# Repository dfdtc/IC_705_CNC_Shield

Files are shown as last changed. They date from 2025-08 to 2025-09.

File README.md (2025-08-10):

## Other languages
- zh_CN [简体中文](README.zh_CN.md)

## Project Overview

This project provides a set of optional features, is highly extensible, and offers a cost‑effective model for an ICOM IC‑705 device shield kit.

---

## Repository & File Structure

This project contains many derived model files, along with some reference models. Therefore: **Please do not simply send the whole folder to a fabrication shop; otherwise you will receive several sets of shields with different configurations and the manufacturing cost will be extremely high.**

### Path Structure

#### Accessories

```
Accessories
```

This folder contains some custom machining accessories as well as modeled standard parts for commercial use (e.g., 4020 aluminum angle code). Purchase or place orders for CNC machining as needed.

#### Machined Parts

```
BasePlate
TopPlate
Handle
```

These files all require CNC machining; order according to the BOM quantities.

#### Aluminum Profile Supports

```
SupportColumn-支撑柱
```

This folder contains model files for aluminum profile supports. They are provided only as references and should not be sent to a CNC or 3D printer.

#### Assembly Explosions & Reference Finished Models

```
AssembleReference
```

This folder contains assembly exploded views and finished product models. They are for reference only and should not be sent to a CNC or 3D printer.

### Naming Convention

Additional features of the derived models are distinguished by suffixes separated with an underscore “_”, e.g.:

- `"底板_开快装板螺纹底孔"` = ordinary base plate + flat-head screw holes + standard tripod quick‑mount threaded bottom holes
- `"底板_开快装板螺纹底孔_沉头_自立"` = self‑standing base plate + countersunk screw holes + standard tripod quick‑mount threaded bottom holes

## Part Machining Recommendations

### 1. Fabrication Notes

#### 1.1  
Because some outsourcing factories provide free edge chamfering / deburring (e.g., CNC-Ai), the top and bottom plate models have no edge chamfers. Pay attention to whether your chosen factory offers this service.

#### 1.2  
The handle model is provided in both un‑chamfered & non‑countersunk versions, as well as chamfered & countersunk variants.

#### 1.3  
Two screw designs are included: tapered countersink and no‑countersink (suitable for cup heads or flat-head screws). Countersunk designs look cleaner but cost a bit more; the no‑countersink version is cheaper but leaves a protruding screw head cap.

#### 1.4  
CNC shops usually offer anodizing and painting, but off‑the‑shelf aluminum profiles may not be available in all colors (see section 2.3). Configure surface treatment options yourself.

#### 1.5  
The handle model is thick and contains a large chamfer; CNC machining time can be long. If cost is an issue, consider 3D printing—strength requirements are fully met.

#### 1.6  
The top plate has M4 holes for fixing the finished Picatinny rails (3/7/11 slots). It’s recommended to thread these yourself during fabrication.

#### 1.7  
Because the base plate is thick, tripod screws cannot directly lock into pre‑machined threaded holes on the machine. Therefore, the base plate offers two configurations: `"开快装板螺纹底孔"` and `"脚架位避让"`.  
- The former already has a 1/4‑20 bottom hole; if your factory supports imperial threading, you can let them thread it, or take the semi‑finished part back to finish it yourself.  
- The latter opens a circular cutout (3.2 cm diameter) at the original tripod screw position, allowing some round mounting brackets to fit into this cutout.

### 2. Aluminum Profile Supports

#### 2.1  
The “EU‑standard 1020 rail” and “EU‑standard 1040 rail” models in the package are only references; do not send them for CNC machining. Find a Taobao shop that cuts 85–88 mm long profiles (the original design is 84.7 mm, so 86/87 mm is recommended to account for machining tolerance and part clearance). Drill holes: M5 on the 1020 rail, M4 on the 1040 rail.

#### 2.2  
Four 1020 rails are required; one 1040 rail is optional and provides extra mounting points and structural support.

#### 2.3  
Commercially available aluminum rails are usually anodized in natural color (some sellers offer black EU‑standard 1020 rails, but not yet for 1040). If you want uniform color, paint as needed, or ask the shop that supplies the profile to provide anodizing/coloring services.

### 3. Installation Notes

#### 3.1  
Because the IC‑705 body bottom is not level, the base plate must have at least a 1.5–2 mm rubber pad around each of the four mounting holes, or use similar thickness rubber washers to achieve sufficient clearance. Otherwise, tightening the mounting screws will impose stress on the machine and the base plate.

### 4. Custom Reference Assembly

#### Derived Model Combination

```
"底板_脚架位避让_沉头_自立" + "顶板_沉头_自立" + "手握_倒角_沉头"
```

#### Factory Choices

- Base/Top Plate: CNC-Ai
- Handle: JLC-CNC (Note: You can also choose CNC-Ai)  
- Antenna Bracket: JLC Sheet Metal  
- Vertical Column: Any Taobao/AliExpress vendor

**Manufacturing Cost (In China, Unit:CNY)**

| Item | Unit Price | Qty | Total |
|---|---|---|---|
| Top Plate | 43 ¥ | 1 | 43 ¥ |
| Bottom Plate | 43 ¥ | 1 | 43 ¥ |
| Handle | 11 ¥ | 2 | 22 ¥ |
| 1020 aluminum post (incl. machining) | 5.3 ¥ | 4 | 21.2 ¥ |
| 1040 aluminum post (incl. machining) | 5.3 ¥ | 1 | 5.3 ¥ |
| Rubber pad | 8 ¥ | 1 | 8 ¥ |
| Fasteners | – | – | ≈30 ¥ |
| Support foot | 12 ¥ | 1 | 12 ¥ |
| **Total** | | | **≈180 ¥** |

#### Tips

I have also 3D‑printed an engineering prototype myself, but I do **not** recommend using 3D printing for this project. The design is optimized for metal CNC; if you wish to use 3D printing, consider other open‑source 3D‑printable shield projects.

---

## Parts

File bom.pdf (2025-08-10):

料名 | 数量 | 用途 | 备注 | 米思米参考料号 | 是否可选
欧标1020铝导轨 | 4 | 立柱，手把安装 | 孔攻丝M5，长度>85mm，建议86/87mm | HFSFIN5-1020
欧标1040铝导轨 | 1 | 立柱 | 孔攻丝M4，长度>85mm，建议86/87mm，可不安装 | | √
20滑块螺母 M5（10x10） | 6+X | 安装手把，以及挂载自定义配件 | 至少买6个 | LNSN6-20-5-100P
橡胶垫 2mm厚，20mm宽 | 合计>6cm | 垫高机器底面 | 多买点吧 | RBNMA2-300
M4 12mm长 6mm头径 | 8 | 机器固定，1040立柱锁定 | 注意为非标头径沉头 | TSARA4-12
M5 12mm长 8mm头径 | 6 | 安装手把 | 注意为非标头径沉头 | TSARA5-12
M5 12mm长 8mm头径 | 16 | 1020立柱锁固 | 注意为非标头径沉头，可以适当选长一点 | TSARA5-15
笔记本电脑支撑脚 | 2 | 垫高机器 | 想买哪款买哪款，基本上都能装
BNC转接头 | X | | 如选择制作转接板，则需要，推荐法兰转接头 | | √
4020铝角码 | X | | 用于固定自定义配件，或装载转接板 | | √
皮卡汀尼导轨 | 1/2 | | 可不安装，自选合适配件，孔距为3/6（竖装）/8CM（横装） | | √
料名 | 数量 | 用途 | 备注 | 是否可选
手握 | 2 | 手把 | | √
顶板 | 1 | 主体结构件
底板 | 1 | 主体结构件
天线板 | 1 | 固定M/N/BNC/SMA四种转接头 | | √
M头天线架 | 1 | 固定M/N四种转接头，二选一 | | √

型材/标准件

机加工件

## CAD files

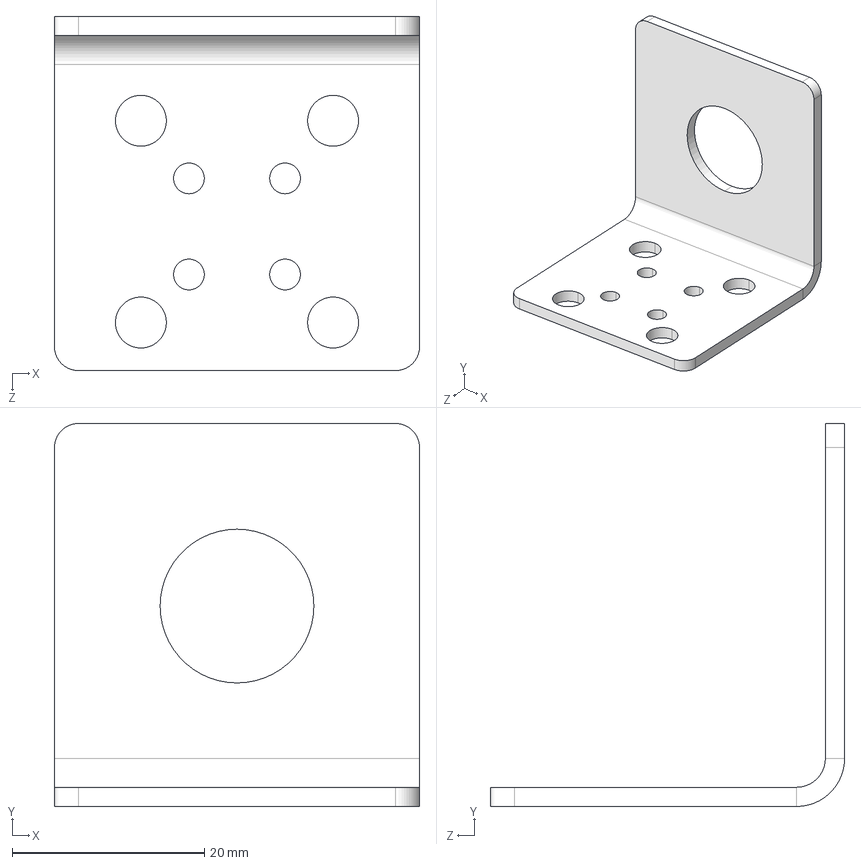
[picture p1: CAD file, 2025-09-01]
Accessories/M头天线架.STEP
38.0 x 39.9 x 36.9 mm

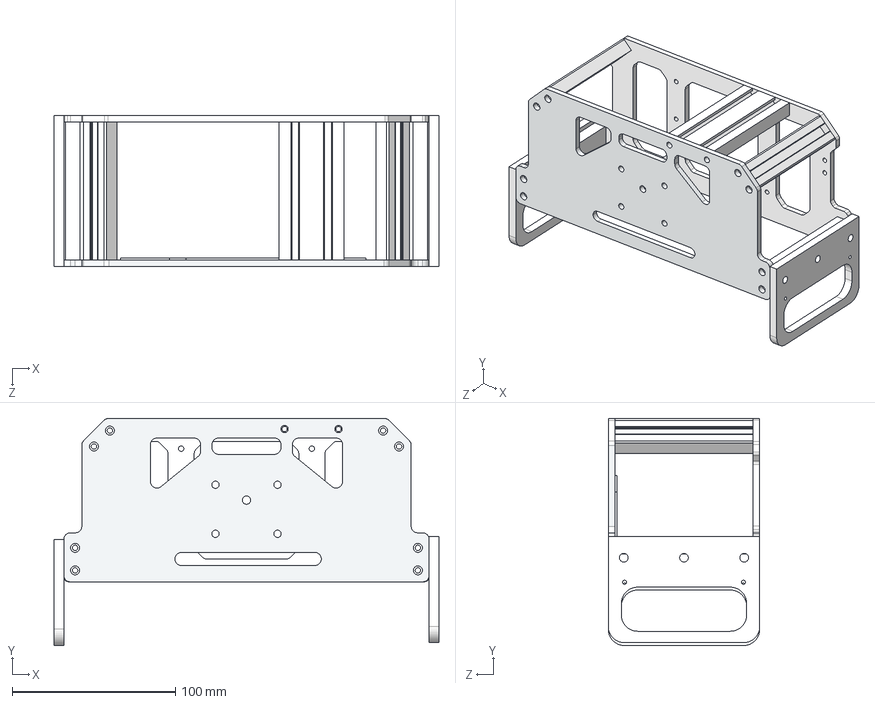
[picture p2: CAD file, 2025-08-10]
AssembleReference/兔笼.STEP
235.6 x 139.0 x 92.7 mm
菁啣V3
階啣V3
欧标1020导轨 x 4
欧标1040导轨
忒挍 x 2
菜え

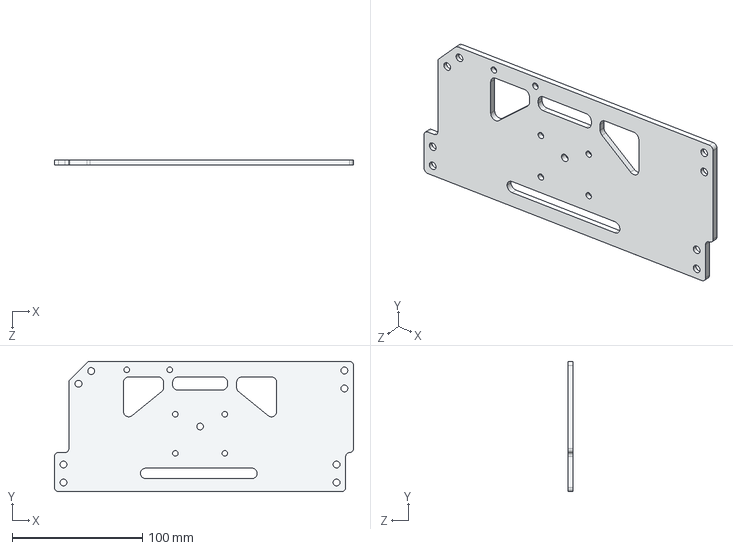
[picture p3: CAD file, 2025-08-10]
BasePlate/底板_开快装板螺纹底孔_沉头_自立.STEP
229.6 x 100.0 x 4.00 mm

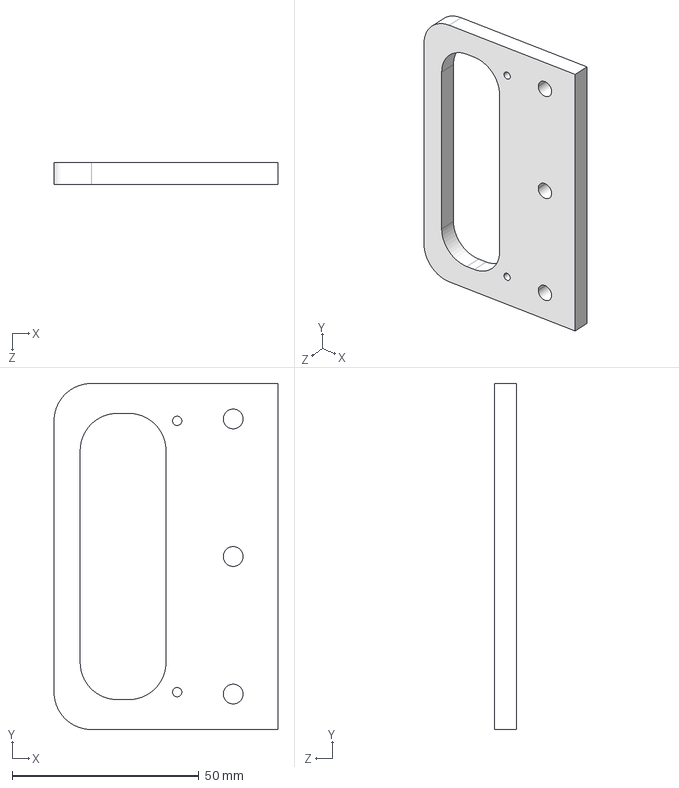
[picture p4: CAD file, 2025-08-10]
Handle/手握.STEP
60.0 x 92.7 x 6.00 mm

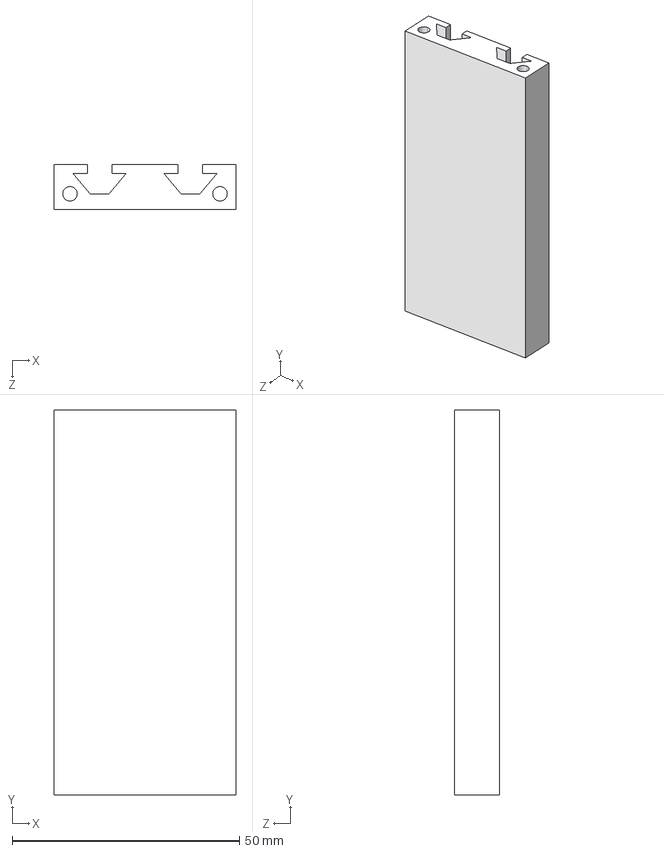
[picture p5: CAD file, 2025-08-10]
SupportColumn/欧标1040导轨.STEP
40.0 x 84.7 x 10.0 mm

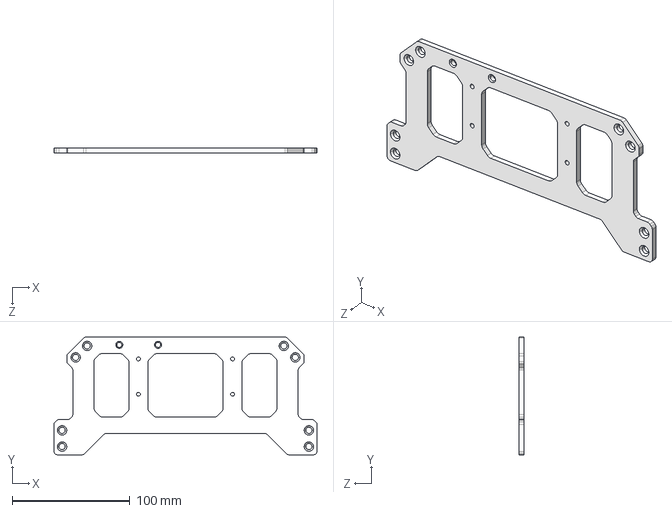
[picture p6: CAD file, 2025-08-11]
TopPlate/顶板_沉头_无天线座固定孔.STEP
223.6 x 100.0 x 4.00 mm

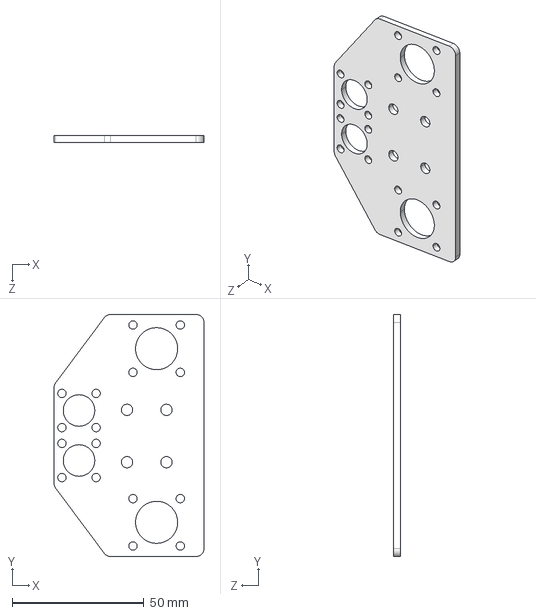
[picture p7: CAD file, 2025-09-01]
Accessories/天线板.STEP
57.0 x 92.0 x 2.50 mm

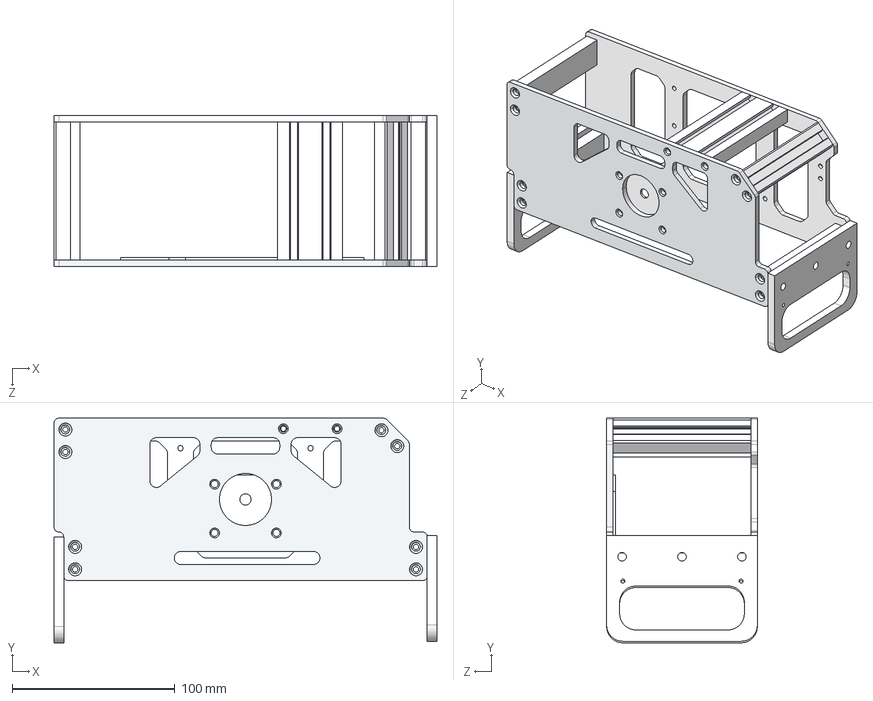
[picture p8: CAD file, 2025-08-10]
AssembleReference/兔笼_自立.STEP
235.6 x 138.2 x 92.7 mm
ｵﾗｰ薹3_ﾎﾞｽﾅｼﾜﾂﾝﾎﾆｿﾗ_ｳﾁﾍｷ_ﾗﾔﾁ｢
顶板V3_沉头_自立
欧标1020导轨 x 4
欧标1040导轨
忒挍 x 2
菜え

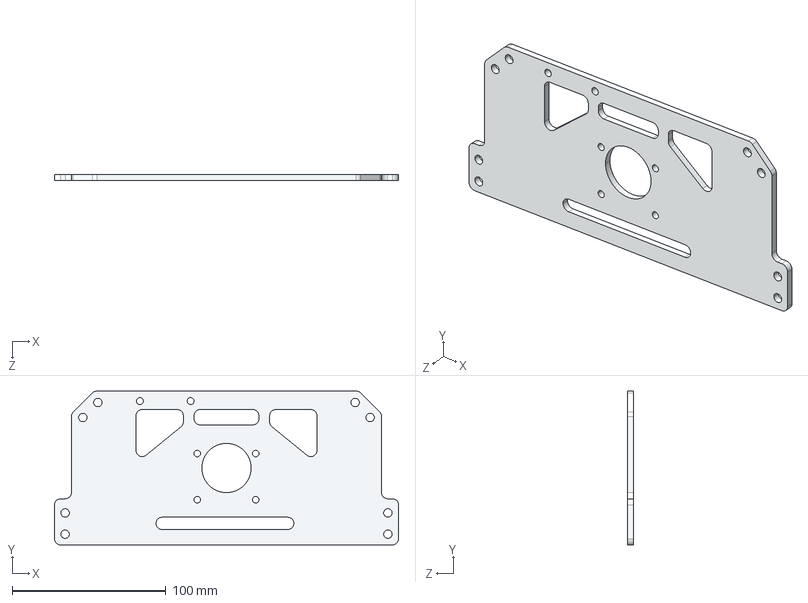
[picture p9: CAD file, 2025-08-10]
BasePlate/底板_脚架位避让.STEP
223.6 x 100.0 x 4.00 mm

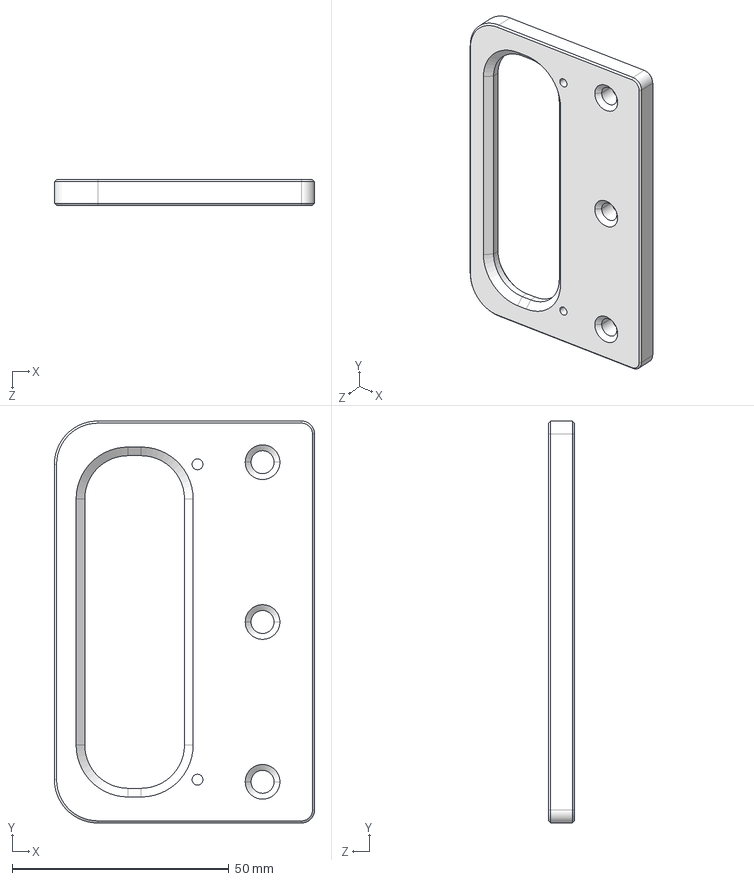
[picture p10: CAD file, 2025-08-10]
Handle/手握_倒角_沉头.STEP
60.0 x 92.7 x 6.00 mm

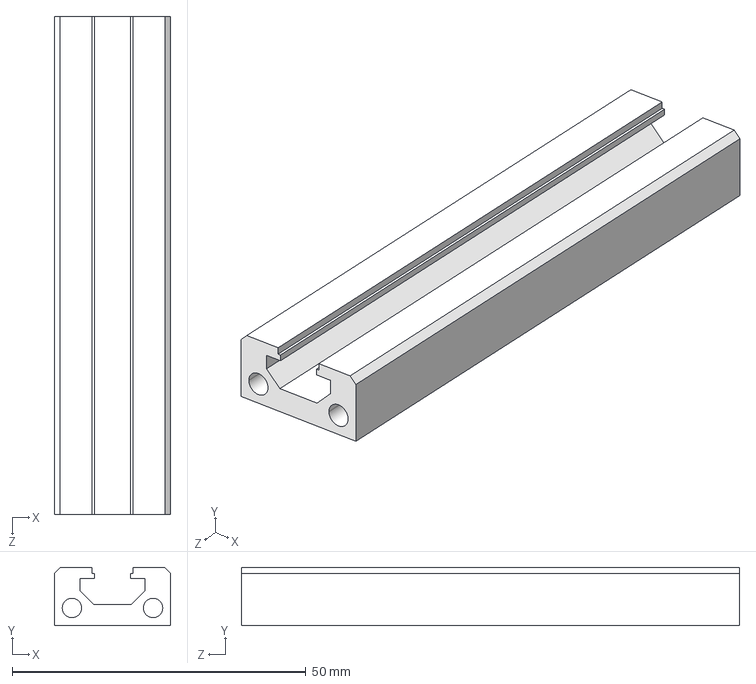
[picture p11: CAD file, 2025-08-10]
SupportColumn/欧标1020导轨.STEP
19.8 x 9.90 x 84.7 mm

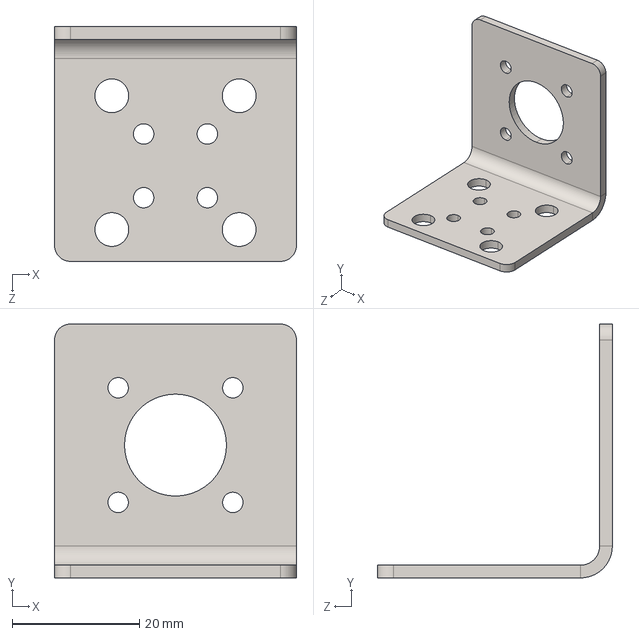
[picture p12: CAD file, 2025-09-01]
Accessories/M头天线架_法兰.STEP
38.0 x 39.9 x 36.9 mm

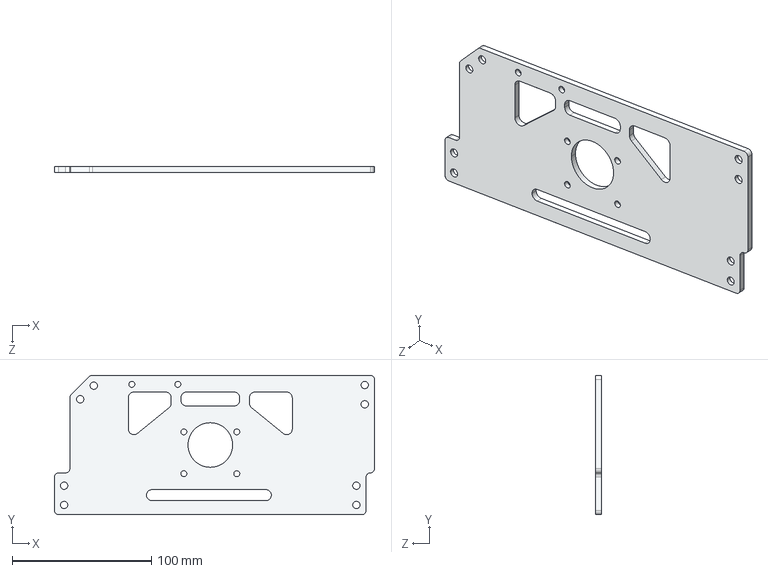
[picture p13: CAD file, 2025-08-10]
BasePlate/底板_脚架位避让_沉头_自立.STEP
229.6 x 100.0 x 4.00 mm

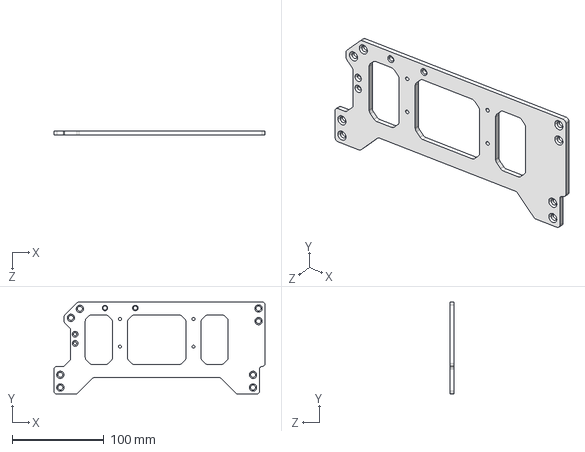
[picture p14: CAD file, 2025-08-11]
TopPlate/顶板_沉头_自立.STEP
229.6 x 100.0 x 4.00 mm

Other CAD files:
TopPlate/顶板.STEP
Accessories/2040铝角码.STEP
BasePlate/底板_脚架位避让_沉头.STEP
TopPlate/顶板_沉头_自立_无天线座固定孔.STEP
BasePlate/底板_开快装板螺纹底孔.STEP
BasePlate/底板_开快装板螺纹底孔_.STEP
TopPlate/顶板_沉头.STEP

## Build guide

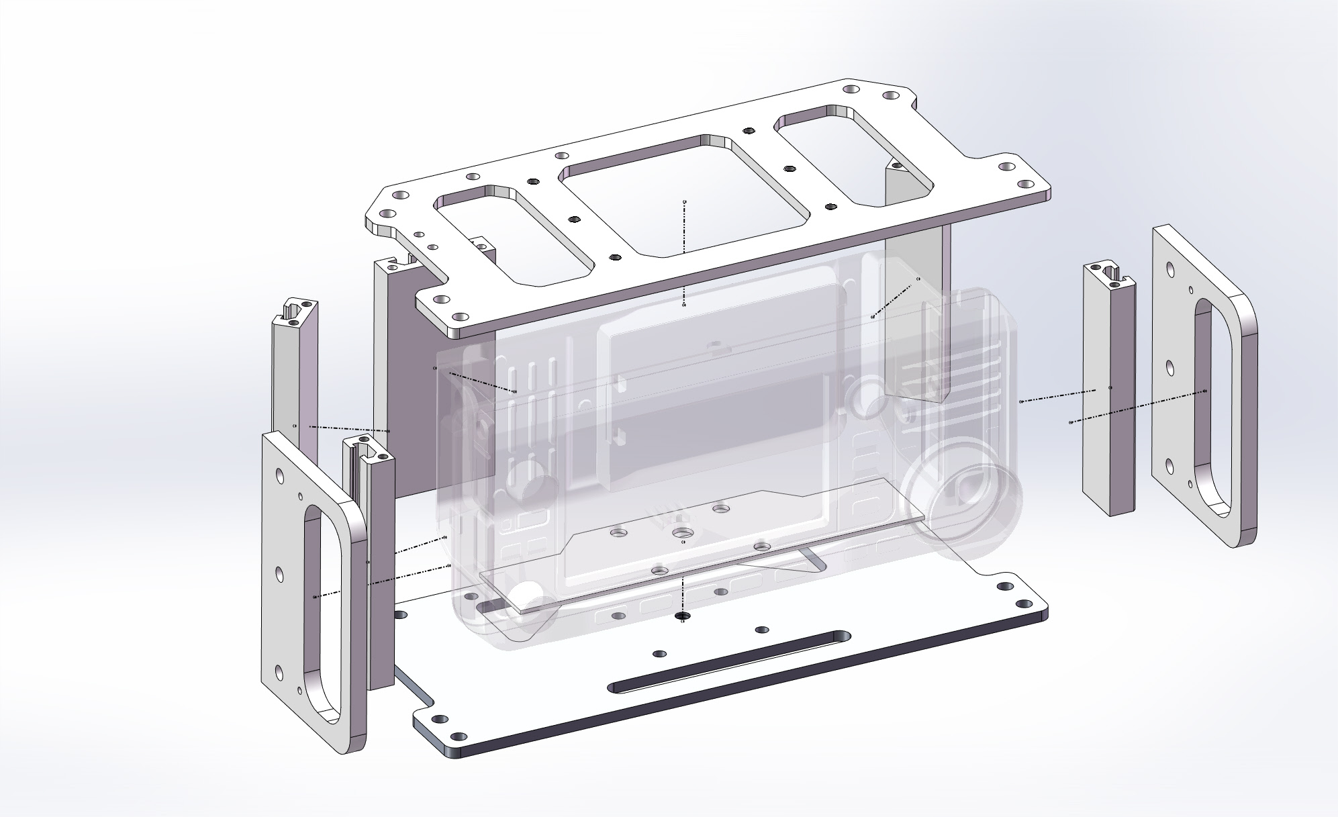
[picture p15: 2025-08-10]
AssembleReference/兔笼.JPG

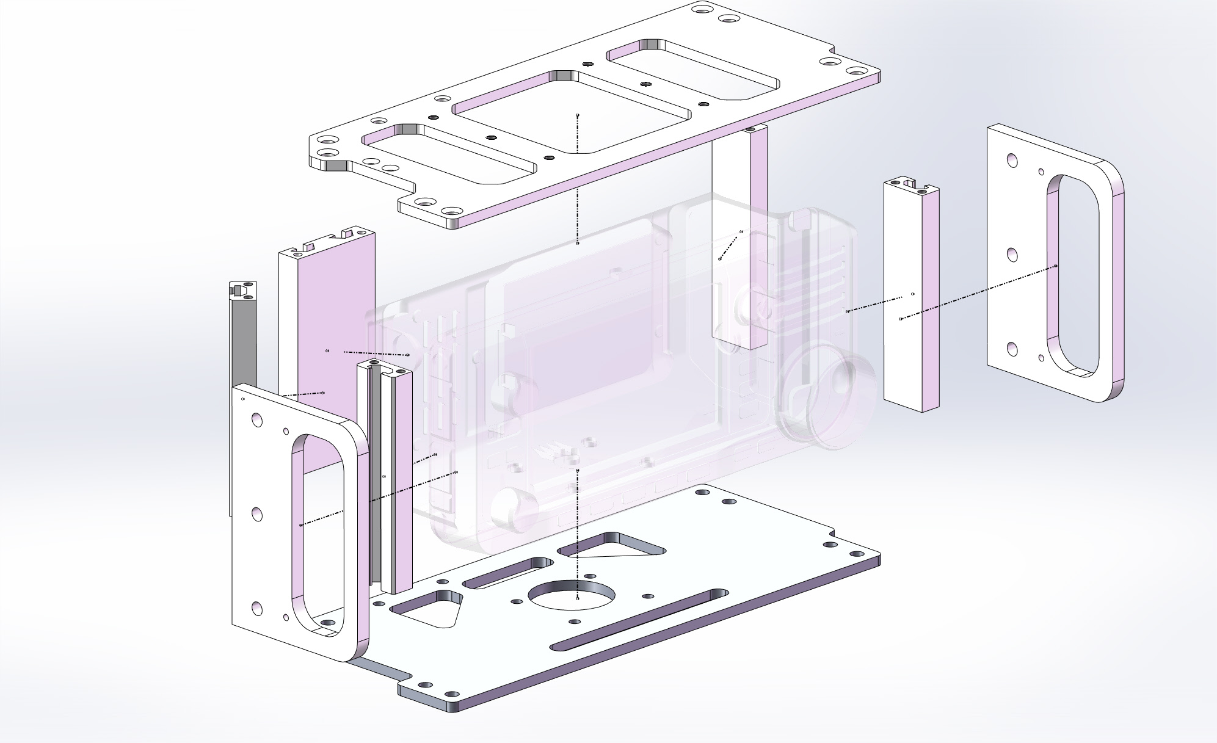
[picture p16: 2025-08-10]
AssembleReference/兔笼_自立.JPG

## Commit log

2025-08-10 [init:project]: 初始化储存库并commit目前全部模型与文档
    [2040铝角码.STEP, M头天线架.STEP, M头天线架_法兰.STEP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]
2025-08-11 [feat:TopPlate]: Cut out to keep clearance to the GPS antenna
    [顶板.STEP, 顶板_沉头.STEP, 顶板_沉头_无天线座固定孔.STEP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]
2025-09-01 [feat:Accessories]: Add rounded corners to metal parts
    [M头天线架.STEP, M头天线架_法兰.STEP, 天线板.STEP]
